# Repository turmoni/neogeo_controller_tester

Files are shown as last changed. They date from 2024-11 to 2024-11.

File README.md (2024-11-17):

# neogeo_controller_tester

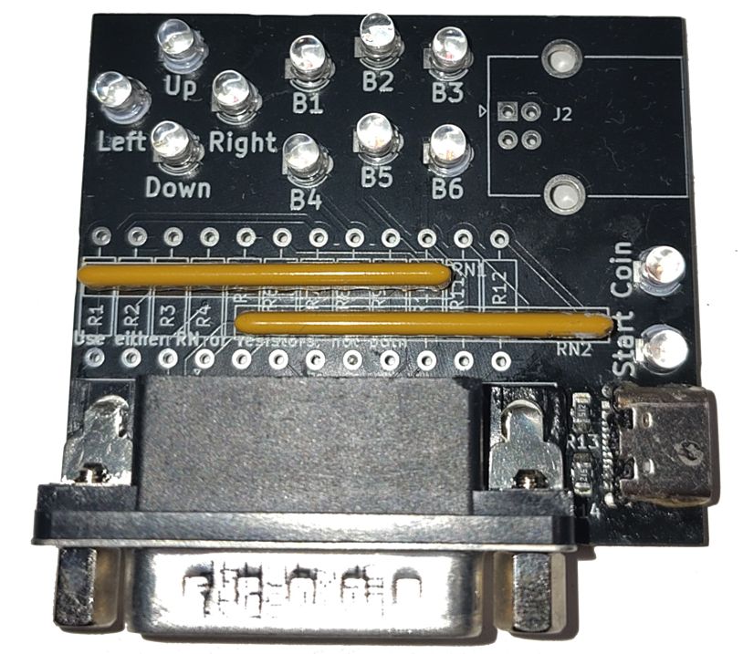
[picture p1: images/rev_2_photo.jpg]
A photograph of an assembled Rev 2 PCB, using the options of two resistor arrays instead of twelve individual resistors, and only having the USB type C port components populated


A simple board that tests the pins of a NeoGeo/Supergun-compatible DA15 controller. Ultimately this is a slightly fancy way of getting 5V through a bunch of LEDs, which will illuminate when the corresponding button is pressed.

I created this for my own use with building [my 9pin2supergun project](https://github.com/turmoni/9pin2supergun), as a simple visual way to check whether my hardware and code were working properly, but I can imagine it being useful to other people.

This is also a bit of a first step in figuring out how to share a KiCad project properly.

## Building one

The KiCad project is in this directory, and for convenience each push gets rendered to the `rendered` directory as a PDF of the schematics, and a set of gerber files. You *should* be able to use [the gerber archive](rendered/gbr.zip) to order boards directly, but for best results you should generate them yourself following your PCB fabricator's instructions (e.g. [for JLCPCB](https://jlcpcb.com/help/article/how-to-generate-gerber-and-drill-files-in-kicad-7)).

This board is designed to be pretty simple to put together, with the option to entirely use through-hole components if you are happy using USB type B for power, or a few surface mount ones if you want to use type C.

The BOM is largely up to your requirements; pretty much any normal LEDs will work, and the resistor value you choose is dependent on your LED and preferred brightness. I have put together [a list on DigiKey](https://www.digikey.co.uk/en/mylists/list/GHFYWIZHWM) for the parts I'm using, but there are still some options:

 * Omit the type C connector and 5.1k resistors if you only want to work with through-hole soldering
 * Omit the type B connector if you don't want it
 * The LED resistors can either be separate individual resistors of your chosen value, or SIP resistor arrays, whichever you prefer/can get your hands on. There should be no functional difference, I just found it tedious dealing with shaping, soldering, and snipping twelve individual resistors in the first revision of this board

## Using

There's not really much to it - plug it into a single power source (type B, type C, or, if it provides power (which it likely shouldn't), your controller), press buttons, see what lights up.

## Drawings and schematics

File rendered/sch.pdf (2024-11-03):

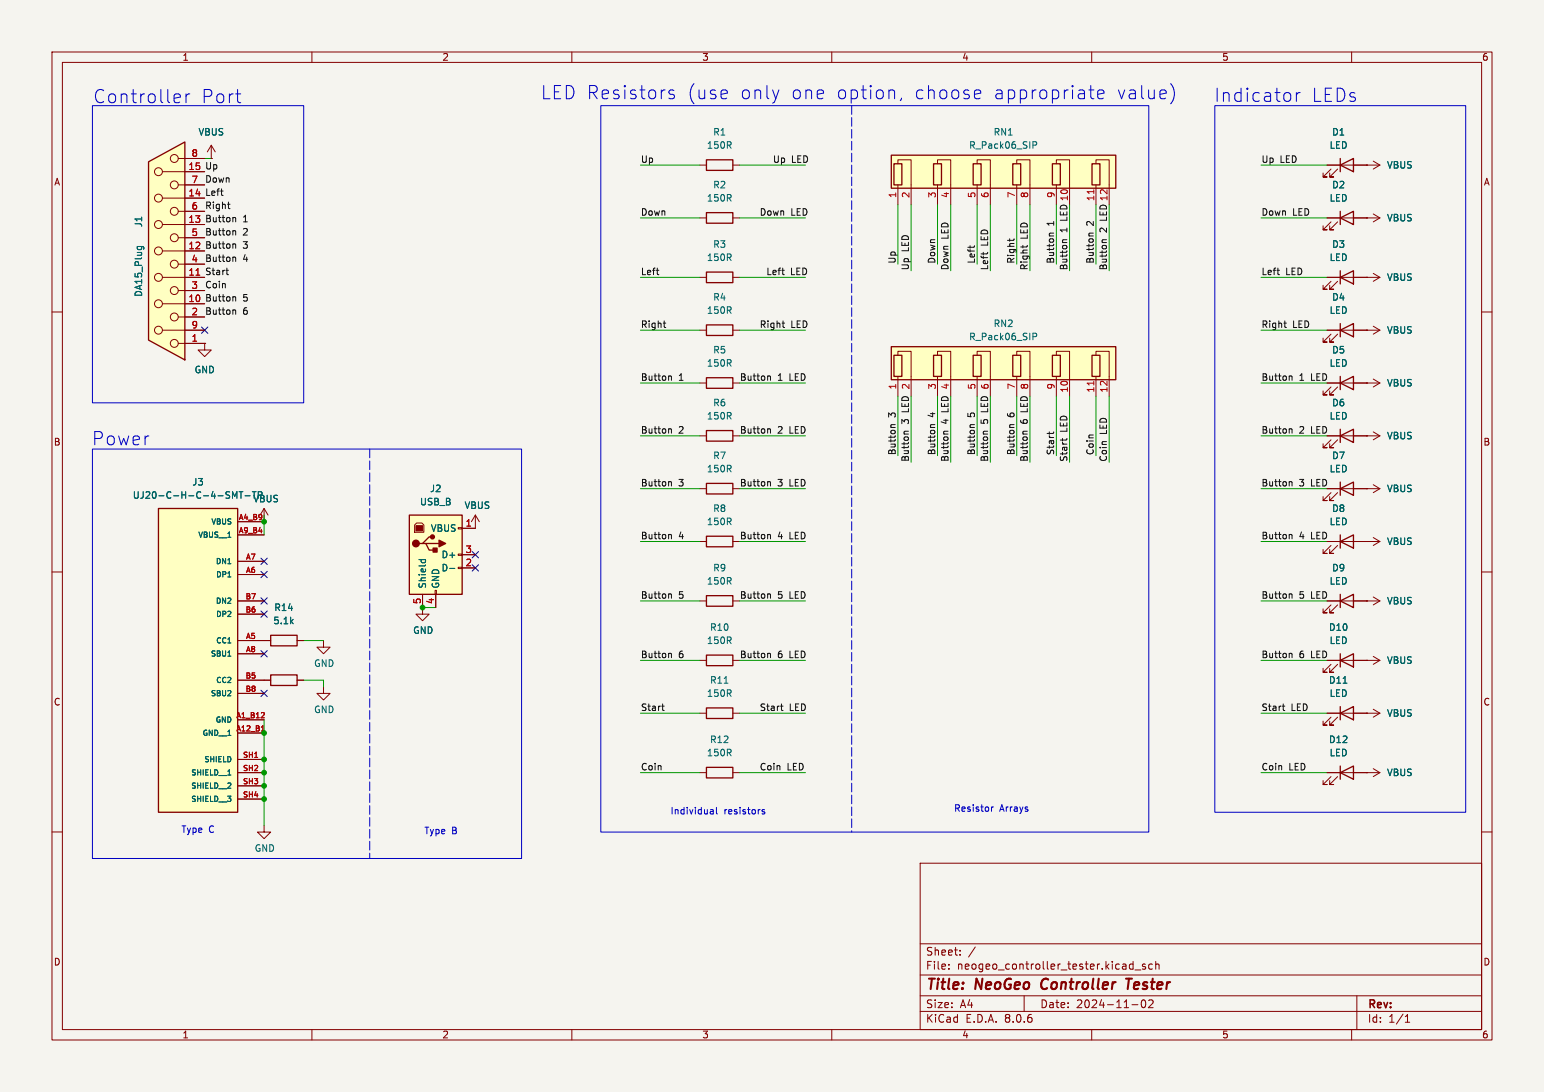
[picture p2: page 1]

Button 6 LED Coin LED

Id: 1/1 Title: NeoGeo Controller Tester File: neogeo_controller_tester.kicad_sch Sheet: / R10

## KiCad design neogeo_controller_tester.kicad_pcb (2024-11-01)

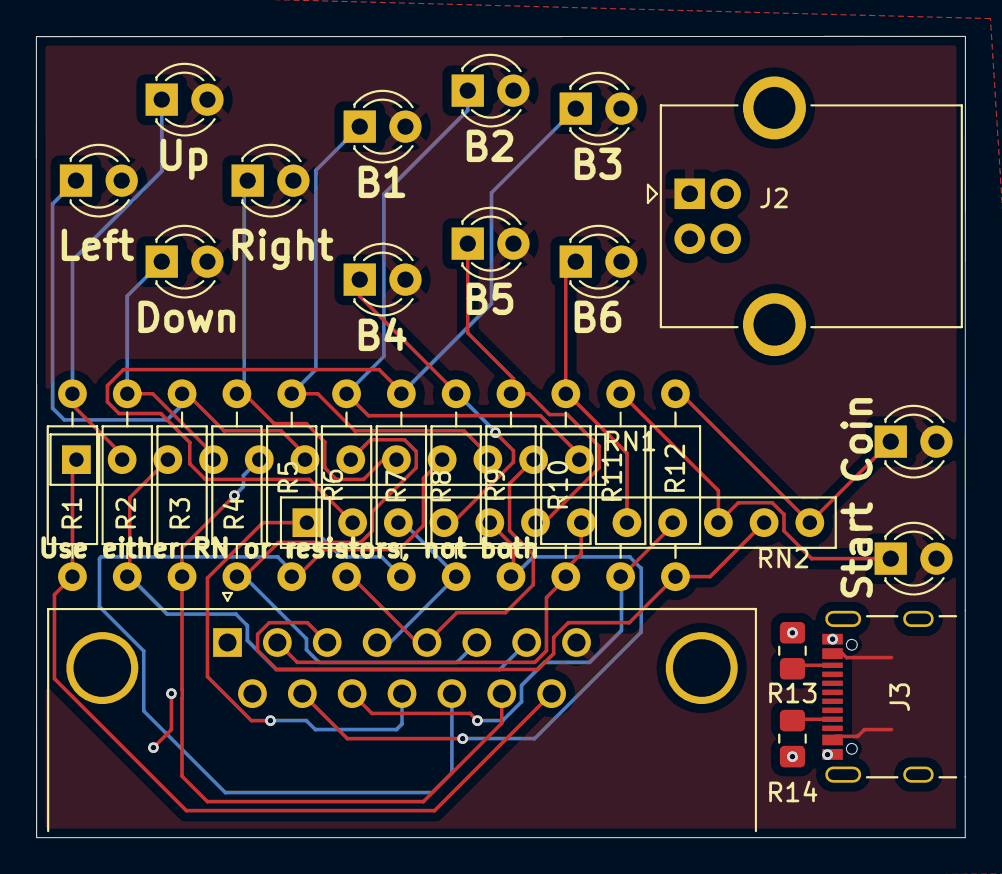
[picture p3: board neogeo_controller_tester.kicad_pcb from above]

Board: 2 copper layers, 51.6 x 44.5 mm, 31 parts (0 on the bottom side), 28 nets.

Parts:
D1, D2, D3, D4, D5, D6, D7, D8, D9, D10, D11, D12: LED; LED_D3.0mm
J1: DA15_Plug; DSUB-15_Male_Horizontal_P2.77x2.84mm_EdgePinOffset7.70mm_Ho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
J2: USB_B; USB_B_OST_USB-B1HSxx_Horizontal
J3: UJ20-C-H-C-4-SMT-TR; CUI_UJ20-C-H-C-4-SMT-TR
R1, R2, R3, R4, R5, R6, R7, R8, R9, R10, R11, R12: 150R; R_Axial_DIN0207_L6.3mm_D2.5mm_P10.16mm_Horizontal
R13, R14: 5.1k; R_0805_2012Metric_Pad1.20x1.40mm_HandSolder
RN1, RN2: R_Pack06_SIP; R_Array_SIP12

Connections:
/Button 1: J1.13, R5.1, RN1.9 (R5.1)
/Button 1 LED: D5.1 (K), R5.2, RN1.10 (R5.2)
/Button 2: J1.5, R6.1, RN1.11 (R6.1)
/Button 2 LED: D6.1 (K), R6.2, RN1.12 (R6.2)
/Button 3: J1.12, R7.1, RN2.1 (R1.1)
/Button 3 LED: D7.1 (K), R7.2, RN2.2 (R1.2)
/Button 4: J1.4, R8.1, RN2.3 (R2.1)
/Button 4 LED: D8.1 (K), R8.2, RN2.4 (R2.2)
/Button 5: J1.10, R9.1, RN2.5 (R3.1)
/Button 5 LED: D9.1 (K), R9.2, RN2.6 (R3.2)
/Button 6: J1.2, R10.1, RN2.7 (R4.1)
/Button 6 LED: D10.1 (K), R10.2, RN2.8 (R4.2)
/Coin: J1.3, R12.1, RN2.11 (R6.1)
/Coin LED: D12.1 (K), R12.2, RN2.12 (R6.2)
/Down: J1.7, R2.1, RN1.3 (R2.1)
/Down LED: D2.1 (K), R2.2, RN1.4 (R2.2)
/Left: J1.14, R3.1, RN1.5 (R3.1)
/Left LED: D3.1 (K), R3.2, RN1.6 (R3.2)
/Right: J1.6, R4.1, RN1.7 (R4.1)
/Right LED: D4.1 (K), R4.2, RN1.8 (R4.2)
/Start: J1.11 (P111), R11.1, RN2.9 (R5.1)
/Start LED: D11.1 (K), R11.2, RN2.10 (R5.2)
/Up: J1.15, R1.1, RN1.1 (R1.1)
/Up LED: D1.1 (K), R1.2, RN1.2 (R1.2)
GND: J1.1, J2.4 (GND), J2.5 (Shield), J3.A1_B12 (GND), J3.A12_B1 (GND__1), J3.SH1 (SHIELD), J3.SH2 (SHIELD__1), J3.SH3 (SHIELD__2), J3.SH4 (SHIELD__3), R13.1, R14.2
unnamed: J3.A5 (CC1), R14.1
unnamed: J3.B5 (CC2), R13.2
VBUS: D1.2 (A), D2.2 (A), D3.2 (A), D4.2 (A), D5.2 (A), D6.2 (A), D7.2 (A), D8.2 (A), D9.2 (A), D10.2 (A), D11.2 (A), D12.2 (A), J1.8, J2.1 (VBUS), J3.A4_B9 (VBUS), J3.A9_B4 (VBUS__1)

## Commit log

2024-11-01 Add PCB files
    [neogeo_controller_tester.kicad_pcb, neogeo_controller_tester.kicad_sch]
2024-11-02 Render schematics and gerbers
2024-11-02 Tidy up schematic
    [neogeo_controller_tester.kicad_sch]
2024-11-03 Add .gitignore for KiCad files
2024-11-03 Only kick off render job if KiCad files have changed, rename from generate_pdfs
